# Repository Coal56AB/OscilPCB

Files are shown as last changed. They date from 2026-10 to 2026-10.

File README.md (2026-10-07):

# OscilPCB — плата двухканального осциллографа

Проект основной платы самодельного осциллографа в Altium Designer. На плате размещены два измерительных канала с BNC-входами, аналоговой обработкой и АЦП AD9288, разъёмы для модуля Zynq-7020 и платы STM32, органы управления и крепления семидюймового LCD. Плата двухслойная, размер контура — 190 × 160 мм.

## Плата

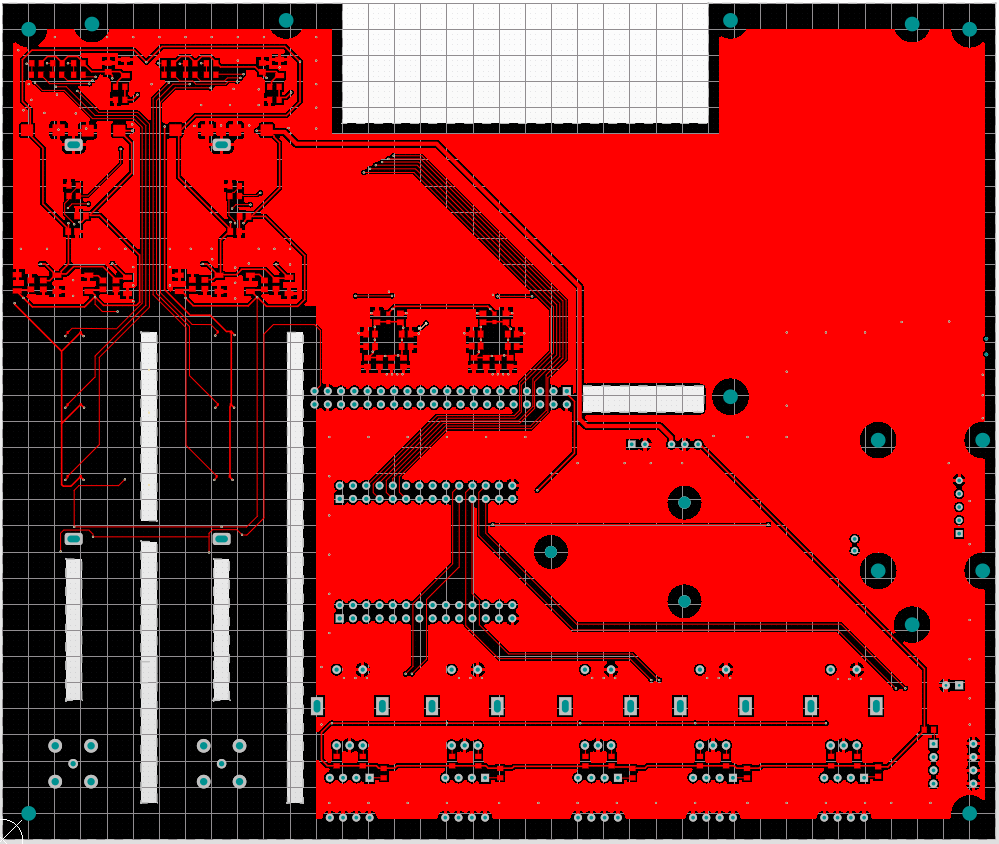
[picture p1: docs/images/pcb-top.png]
Top платы


*Разводка верхней стороны: фильтрующие конденсаторы и подтягивающие резисторы.*

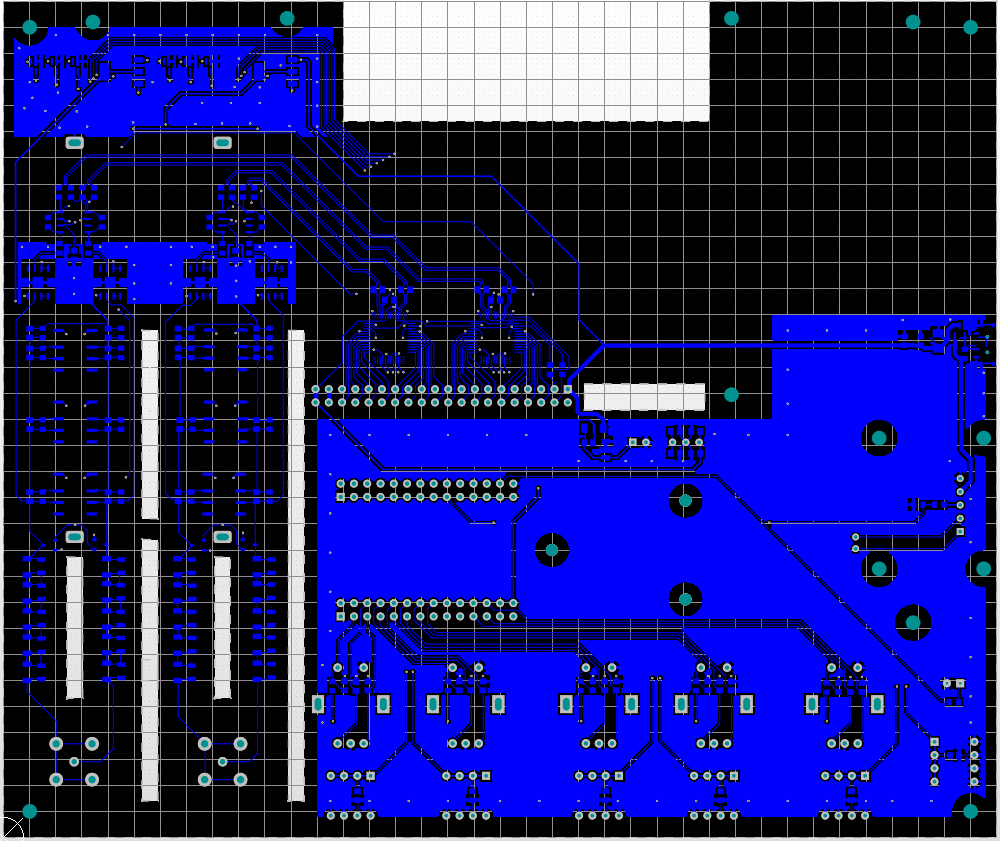
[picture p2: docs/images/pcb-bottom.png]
Bottom платы


*Разводка нижней стороны: входные тракты каналов, АЦП, питание и соединения с Zynq, STM и интерфейсом.*

## 3D-модель

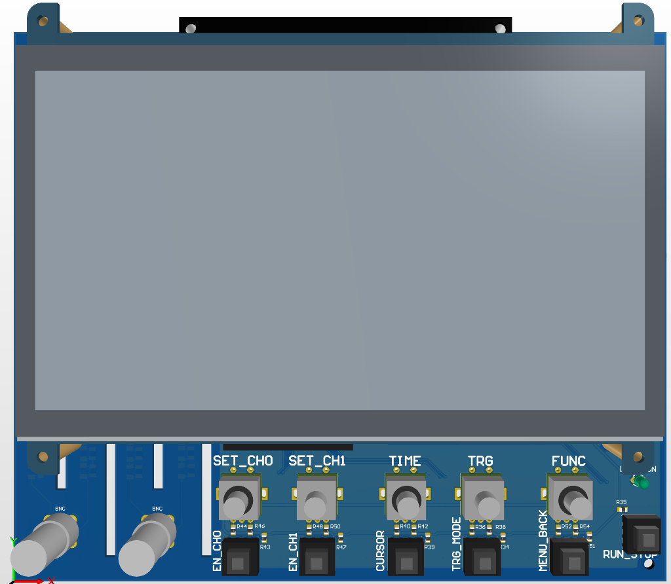
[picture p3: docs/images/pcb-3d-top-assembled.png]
3D-модель с LCD и Zynq, верхняя сторона


*Верхняя сторона.*

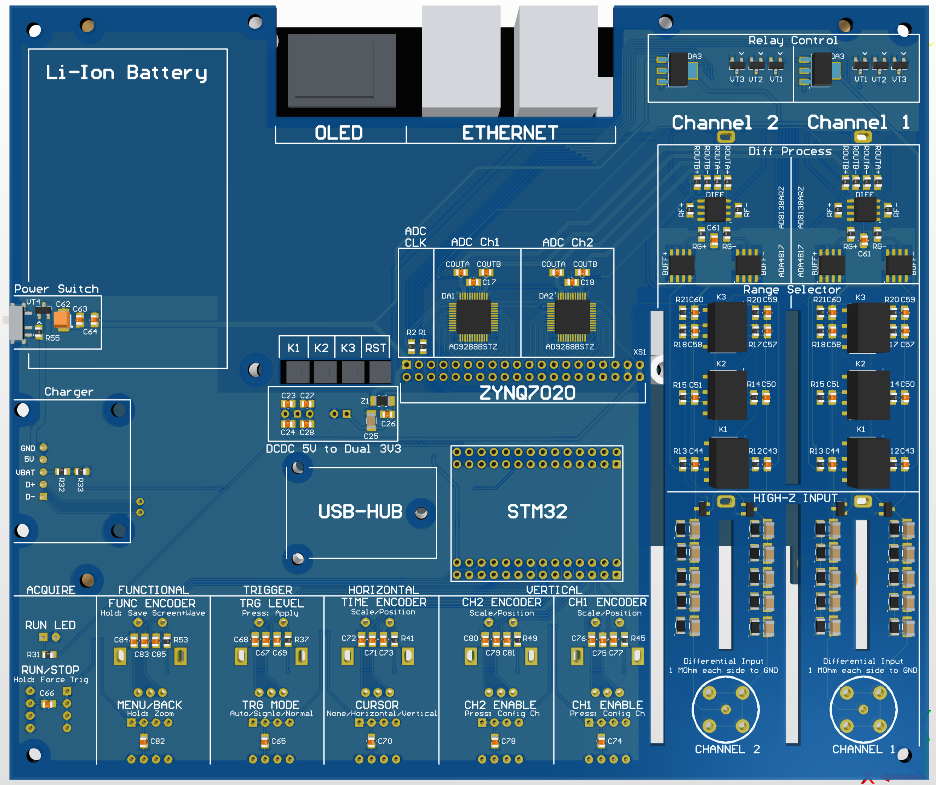
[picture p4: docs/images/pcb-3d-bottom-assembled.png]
3D-модель с LCD и Zynq, нижняя сторона


*Нижняя сторона.*

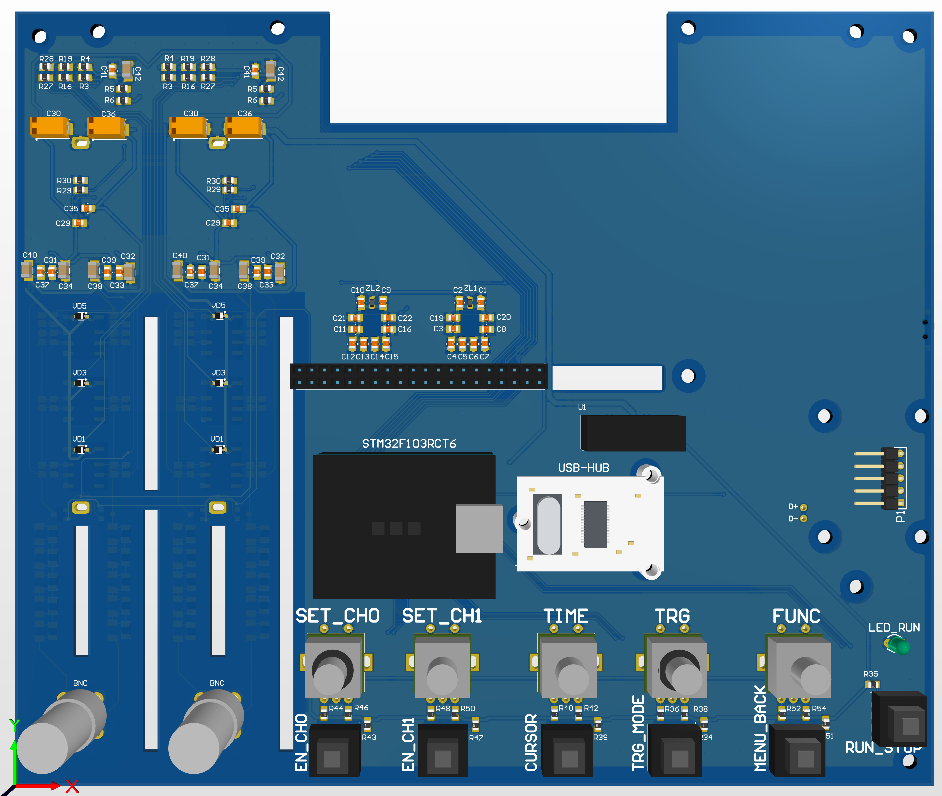
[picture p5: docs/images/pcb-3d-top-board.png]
3D-модель без LCD и Zynq, верхняя сторона


*Верхняя сторона без LCD и Zynq.*

## Файлы проекта

- `AnalExtend/AnalExtend.PrjPcb` — проект Altium Designer; в этой же папке находятся PCB и схемы.
- `Lib/` — библиотеки символов, посадочных мест и 3D-моделей. Подробности для разработчика приведены в [Lib/DEVELOPMENT.md](Lib/DEVELOPMENT.md).
- `Manufacture/` — Gerber-файлы и файлы сверловки.

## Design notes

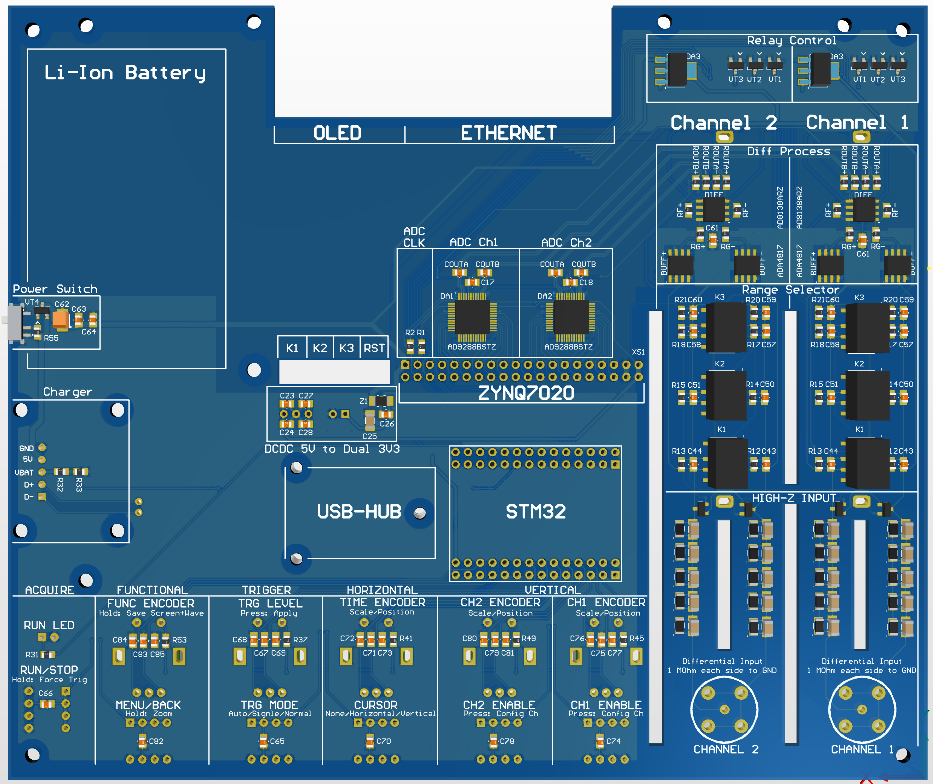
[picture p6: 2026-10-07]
docs/images/pcb-3d-bottom-board.png

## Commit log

2026-10-02 init
    базовый тракт сделан, надо перепроверить и доьбвать решелки на управление диапазонами
    а также добавить контроллер, какой пока не знаю
    [AnalExtend.PcbDoc, AnalExtend.PrjPcb, AnalExtend.SchDoc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]
2026-10-02 сделана компоновка, добавлены 3д платы цинка и экранчика
    надо допилить динамический диапазон, контроллер и разводку
    [AnalExtend.PcbDoc, AnalExtend.PrjPcb, AnalExtend.SchDoc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]
2026-10-03 тракт измерения доделан, осталось сделать схему контроллера
    - переделан тракт на другиз микросхемах для большей полосы пропускания
    - добавлены релешки для управления диапазоном
    - красивое форматирование DiffMeasure
    - всё разведено, что есть в схеме
    [AnalExtend.PcbDoc, AnalExtend.PrjPcb, AnalExtend.SchDoc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]
2026-10-03 Всякое мелочное
    [AnalExtend.PcbDoc, AnalExtend.SchDoc, DiffMeasure.SchDoc]
2026-10-03 Начато добавление контроллера и интерфейсов
    Но крашится при редактировании pcb footprint
    [AnalExtend.PcbDoc, AnalExtend.PrjPcb, AnalExtend.SchDoc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]
2026-10-04 Вроде доделано в первом приближении, надо поискать недоработки и пофиксить их
    [AnalExtend.PcbDoc, AnalExtend.SchDoc, Interfaces.SchDoc]
2026-10-04 Добавлено шеклографии и мелкие фиксы
    [AnalExtend.PcbDoc, Interfaces.SchDoc]
2026-10-04 Доработки по диффпаре, и rules и подписано шеклографией управление
    [AnalExtend.PcbDoc, AnalExtend.SchDoc, Interfaces.SchDoc]
2026-10-04 Переделана цепь включения питания
    Добавлен мосфет которым управляем переключатель, т.к. сам переключатель слабенький для коммутации 5В
    [AnalExtend.PcbDoc, AnalExtend.SchDoc]
2026-10-05 Еще фиксы +output, плата выбрана синей
    Этот вариант заказал в электроконнект (но сам проект после отправки еще чуть косметически изменился)
    [AnalExtend.GBL, AnalExtend.GBO, AnalExtend.GBP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]
2026-10-05 Обновлена модель LCD и Цинк
    Изменен цвет текстолита на реалистичный и добавлены вырезы в LCD
    [AnalExtend.PcbDoc, AnalExtend.PrjPcb, AnalExtend.SchDoc]
2026-10-05 фиксы шелкографии
    [AnalExtend.PcbDoc]
2026-10-05 бля какой-то проеб с полигонами случился...
    поправил и зафиксировал их, но все равно обидно что заказал с кривыми, хз как проглядел
    [AnalExtend.PcbDoc]
2026-10-06 фикс либы - дифф ОУ заменен на корректный AD8138ARZ
    [AnalExtend.PcbDoc, DiffMeasure.SchDoc]
2026-10-07 Добавить README с видами платы и 3D-модели
    Описаны назначение и состав проекта. Добавлены виды двух сторон платы и четыре изображения 3D-модели с видимыми и скрытыми LCD и Zynq.
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2026-10-24 Сохранены текущие правки платы и библиотек
    Зафиксированы изменения платы, двух листов схемы и исправления посадочных мест с отчётом проверки перед объединением с актуальным master. Исходное состояние сохранено отдельным коммитом без изменения опубликованной истории.
2026-10-27 Уточнены геометрия платы и модели компонентов
    В AnalExtend/AnalExtend.PcbDoc обновлены геометрия площадок и участков трасс, а также трёхмерные тела органов управления. В Lib/Oscill.PcbLib и генераторе библиотеки кнопка представлена на переходник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
2026-10-27 Добавлен печатный корпус со сборкой SolidWorks
    В oscill_box/ добавлены две половины корпуса, откидная подставка, колпачок выключателя, задняя прозрачная панель и справочные модели электроники. Сборка SolidWorks содержит разложенное и сложенное по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
2026-10-27 Усилен корпус и состыкован разъём зарядника
    Добавлены угловые усиления, косынки со скруглениями R0,8/R1,5 и свободные кромки корпуса. Нижняя опора PCB доведена до внутреннего контура.
    Зарядник опущен на 3,4 мм и смещён на 0,51 мм для стыковки J8/P1. Опоры 2,6 мм рассчитаны под M2; окно USB перенесено вслед за модулем. Обновлены реальные детали SOLIDWORKS и сборка.
    Проверены размеры CAD, основные проход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
2026-10-27 Исправлен экспорт корпуса в STL
    Косынки передаются из геометрического генератора в SolidWorks без дублирования стойки и входного скругления посадки втулки. Кольцо перекрытия связывает усиление с родительской деталью. Детали корпуса и четыре STL отражают актуальную геометрию усилений и посадку зарядника.
    Импорт STEP использует общие явные настройки для усилений и справочных моделей. Э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
2026-10-27 Уточнены панель управления и скос экрана
    На накладке номера каналов размещены сверху в утолщённой цветной окантовке BNC. Названия и приглушённые подсказки энкодеров приближены к колпачкам, фоновые зоны центрированы по органам управления. Ув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
    Справочные к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
2026-10-27 Уточнены скос экрана и окантовки RUN/STOP
    Внутренняя и верхняя кромки экранного окна имеют скругление R0,4. Наклон скоса рассчитан по огибающей бортика, чтобы минимальный световой проём совпадал с активной областью LCD и сохранял её углы отк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
    Скругление окна расположено перед крепёжными усилениями в дереве передней половины. Расчётный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
2026-10-27 Исправлен внутренний контур колец BNC
    Фоновая заливка внутри цветных колец закрывает нижний край плашек с номерами каналов. Внутренняя кромка остаётся круглой в месте соединения кольца и плашки.
    Накладка панели в сборке SolidWorks содержит исправленный рисунок.
2026-10-28 Стабилизировать сессию CAD и экспорт STL
    Последовательные операции построения корпуса используют одну COM-сессию SolidWorks, общую с управлением надстройкой CAM.
    Если штатная сетка SolidWorks содержит складки или незамкнутые рёбра, экспортёр повторно триангулирует валидный STEP той же детали. Перенос в положительные координаты и сварка вершин вынесены в общий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
2026-10-28 Уменьшить люфт ползунка питания
    Буртик ползунка скользит в открытом к плате кармане с рельсами толщиной 0,9 мм. Наружный стержень получил отдельную направляющую с заходными фасками для скруглённых корней; боковые усилия воспринимае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
    Поперечный зазор уменьшен до 0,15 мм на сторону, осевой — до 0,12 мм. Продольный запас 0,35 мм у концов хода задаётся независимо. Гнездо под штырё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
